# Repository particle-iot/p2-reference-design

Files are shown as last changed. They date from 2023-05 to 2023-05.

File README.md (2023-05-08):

# P2 evaluation board reference design

This board is a reference design for creating your own P2 base board. 

It is not available for purchase as a completed product; if you are interested in prototyping with the P2 we recommend using the Photon 2, which contains a P2 module on it, and has the same pinouts as the Feather connectors on this board.

This is a simple breakout board for Particle's P2 Wi-Fi module. It breaks out all of its pins via easy to use headers. The board features a USB port, a barrel jack power connector, buttons, and RGB LED as well as Feather, Grove, and Qwiic connectors for prototyping with external sensors, displays, etc..

- [P2 Datasheet](https://docs.particle.io/reference/datasheets/wi-fi/p2-datasheet/)
- [Particle hardware library for Eagle CAD](https://github.com/particle-iot/hardware-libraries)

## Schematic

The schematic files (*.sch) in Eagle CAD format are included in the **eagle** directory in this repository.

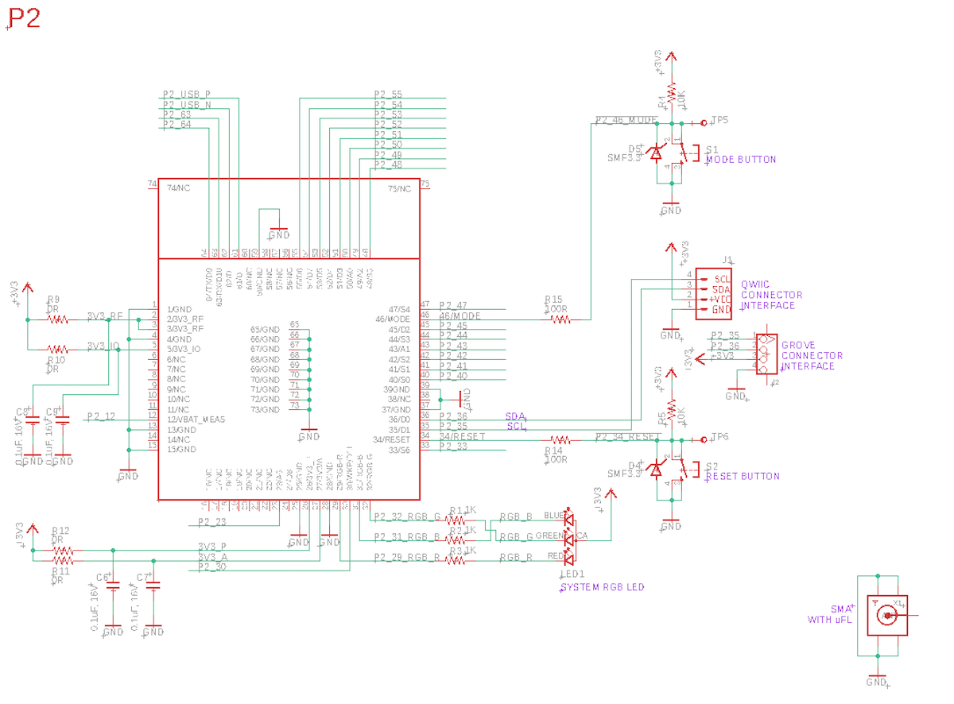
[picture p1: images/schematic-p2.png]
Schematic P2


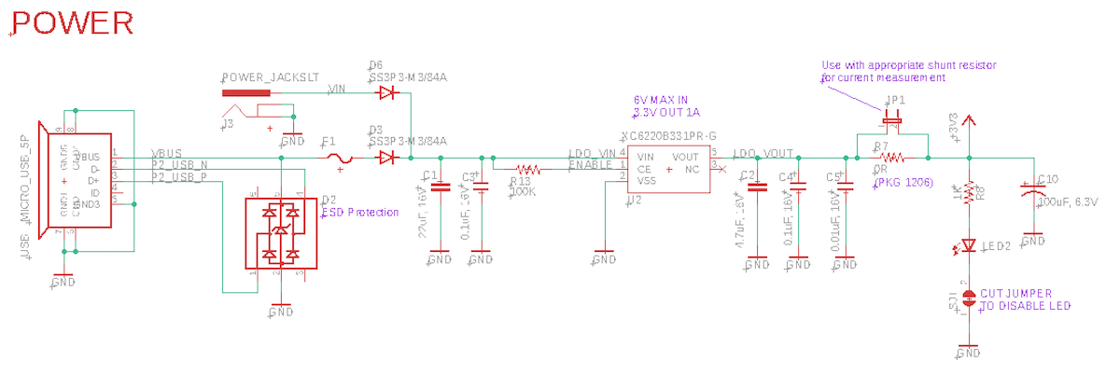
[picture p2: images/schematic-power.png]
Power


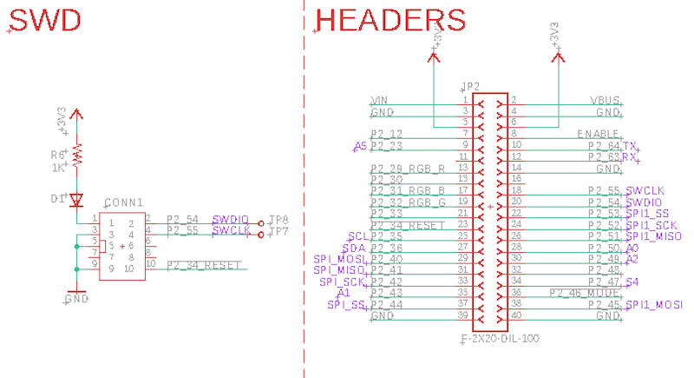
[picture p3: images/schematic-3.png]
SWD and Headers


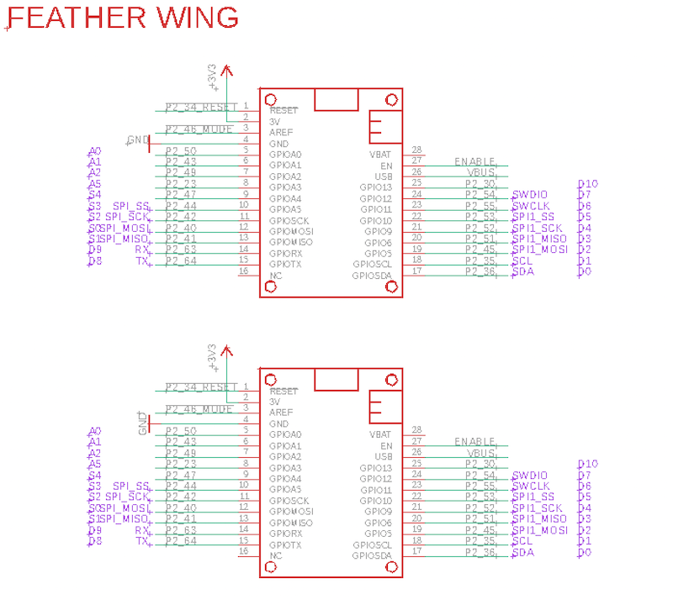
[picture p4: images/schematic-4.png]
Feather


## Board layout

The board layout files (*.brd) in Eagle CAD format are included in the **eagle** directory in this repository. 

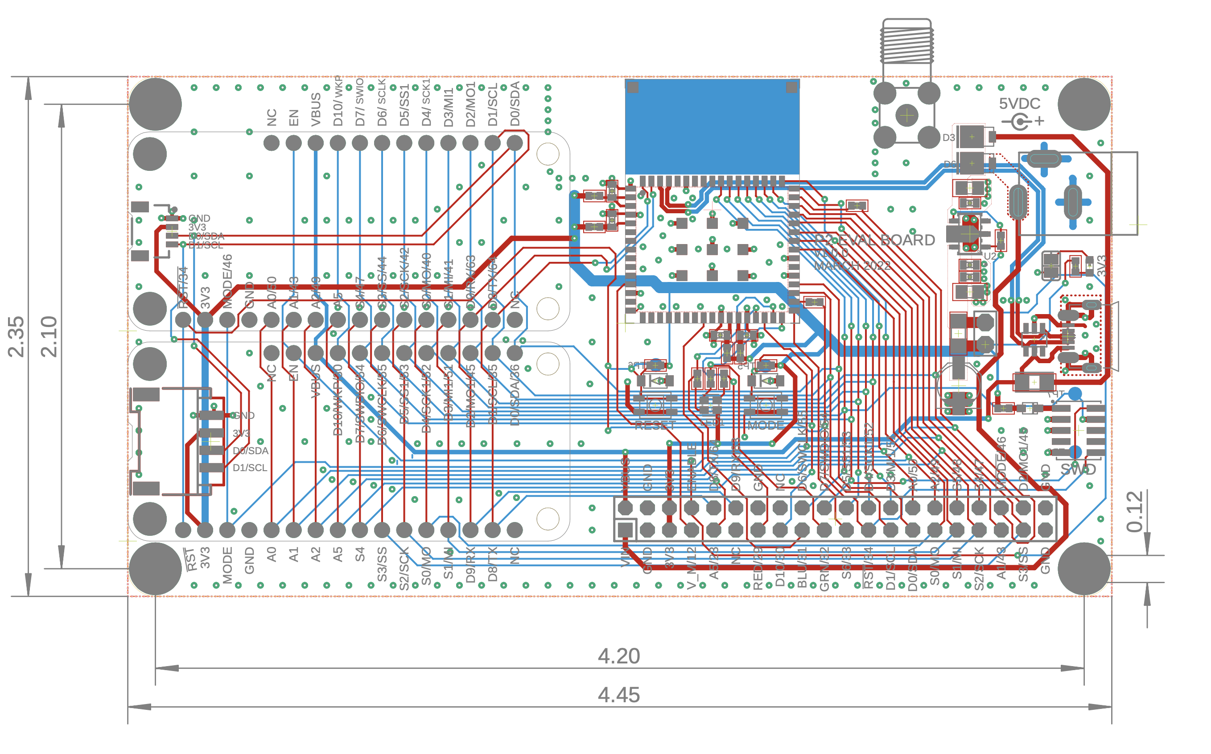
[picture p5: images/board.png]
Board layout


This is a 4-layer board, so you won't be able to edit the board using the free version of Autodesk Eagle, however gerber files are included in the **gerbers** directory if you want to fabricate this exact board.

The recommended stack-up is:

- DIELECTRIC = 3.61 at 1GHz
- TOP LAYER = 1.7MIL (1 OZ)
- PREPEG = 7.96MIL
- LAYER 2 = 0.68MIL (0.5 OZ)
- CORE = 47MIL
- LAYER 3 = 0.68MIL (0.5 OZ)
- PREPEG = 7.96MIL
- BOTTOM LAYER = 1.7MIL (1 OZ)

## Description

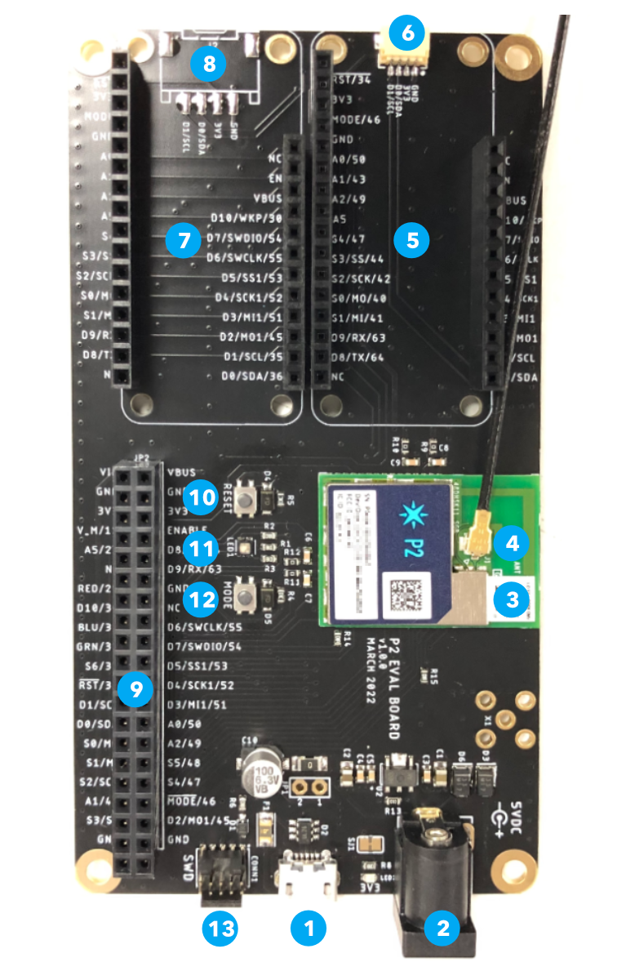
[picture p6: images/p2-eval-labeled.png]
Board labeeled


| Label | Description |
| :---: | :--- |
| 1 | USB |
| 2 | 5V Power In (optional) |
| 3 | P2 Module |
| 4 | External Wi-Fi and BLE antenna (optional) |
| 5 | Feather expansion connector |
| 6 | Qwiic I2C connector |
| 7 | Feather expansion connector |
| 8 | Grove expansion connector |
| 9 | Expansion header|
| 10 | RESET button |
| 11 | RGB LED |
| 12 | MODE button|
| 13 | SWD debugging connector |

If powering by USB, 500 mA is required. This a compatible with most USB hubs, computers, laptops, and chargers, but will not work with some low-power USB ports on some keyboards.
 
The P2 includes a built-in trace antenna that is used for both BLE and Wi-Fi. A U.FL connector is provided for an external antenna, if desired. The antenna selection must be made in software; the P2 will not automatically switch between built-in and external antennas. If using an external antenna, a dual-band (2.4 GHz and 5 GHz) antenna is required. The external antenna doesn't have to explicitly include BLE support, as the BLE frequencies are the same as 2.4 GHz Wi-Fi so all dual-band Wi-Fi antennas are compatible.

## Building user firmware

As of the time of writing (June 2022), P2 firmware can only be compiled using the cloud compiler.

### Using Particle Workbench

When using Particle Workbench, use the **Particle: Launch CLI** option from the Command Palette (Command-Shift-P or Ctrl-Shift-P). Then use the Particle CLI to generate a binary, as described in the next section.

### Using the Particle CLI

From the Particle CLI, you can use a command such as:

```
particle compile p2 . --target 5.3.1 --saveTo firmware.bin
```

Note that you must specify a target system version when building for the P2. If an upgrade of Device OS is required, it will be updated OTA.

### Using the Web IDE

From the Web IDE, select the Devices icon, then your P2 device, then target an appropriate firmware version, such as 5.3.1. If an upgrade of Device OS is required, it will be updated OTA.

## Expansion connectors

### Expansion header

If you are prototyping your own custom design you may want to use the 40-pin expansion header. It's a standard 20x2 female header, 0.1" pitch, that can accept male header pins or prototyping wires.
    
Expansion header

See the [P2 Datasheet](https://docs.particle.io/reference/datasheets/wi-fi/p2-datasheet/) for details about the pins. The gold boxes indicate the P2 pin numbers.

### Feather expansion

Feather connector

There are two socket for [Feather accessory boards](https://docs.particle.io/hardware/expansion/feather/). These are only for use with displays, sensors, storage, etc.. 

You must not plug a Particle device such as an Argon or Boron in this socket, as the device may be permanently damaged.

This will work with most Feather boards, however:

- The P2 does not support ADC inputs A3, A4, and A5.
- The P2 does not work with Feather accessories that use SPI1 on the Argon or Boron D pins.
- Some pins have different names which may require minor source code modifications. This includes and code that used Argon or Boron pins A3, A4, A5, or D8.

The pinouts of the Feather accessory socket correspond to pinouts of the Photon 2. See the [Photon 2 Datasheet](https://docs.particle.io/reference/datasheets/wi-fi/photon-2-datasheet/) and the [Argon to Photon 2 migration guide](https://docs.particle.io/hardware/migration-guides/photon-2-argon-migration-guide/) for more information.

Some pins in the same positions are named differently between the Argon/Boron and the Feather accessory socket/Photon 2:

| Argon Name | P2 Feather Socket Name |
| :---: | :---: |
| A3 | A5 |
| A4 | S4 |
| A5 | S3 |
| D8 | D10 |

Additionally, `D` pin aliases `D8` and higher are different, however these names are rarely used.

Photon 2 vs. Argon Comparison

### Qwiic connector

[Qwiic](https://docs.particle.io/hardware/expansion/qwiic/) is a 3.3V I2C standard developed by SparkFun and adopted by other manufacturers. It's also compatible with Adafruit Stemma Qt expansion devices. You can use this to add displays, sensors, etc. and multiple devices can be connected to a single Qwiic port, as accessory boards have two connectors for chaining multiple sensors.

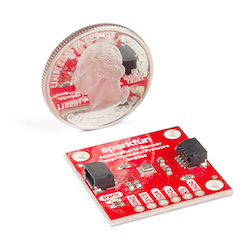
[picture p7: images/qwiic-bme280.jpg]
Qwiic sensor


### Grove connector

The Grove connector allows [Grove accessories](https://docs.particle.io/reference/datasheets/accessories/gen3-accessories/#grove-starter-kit) to be added. Pins D0 and D1 are present on the connector. This allows the use of Grove I2C sensors.

If you are not using I2C elsewhere (Feather, Qwiic), you can use these pins as digital GPIO, or as analog inputs.

| Pin | I2C | Digital | Analog |
| :---: | :---: | :---: | :---: |
| GND | | | |
| 3V3 | | | |
| D0/SDA | SDA | D0 | A3 |
| D1/SCL | SCL | D1 | A4 |

Grove sensor

## SWD debugging connector

The P2 eval board has a 10 pin debug connector that exposes the SWD interface of the MCU. This can be used to program the bootloader, device OS, or the user firmware using any standard SWD tools including the Particle Debugger, Segger J/LINK, or other CMSIS-DAP debuggers. It can also be used for source-level debugging using Particle Workbench.

Note that SWD is shared with GPIO pins D6 and D7, and by default SWD is only enabled while the bootloader is running, immediately at boot, and when in DFU mode (blinking yellow). Only Debug builds in Workbench have SWD enabled in when user firmware is running.

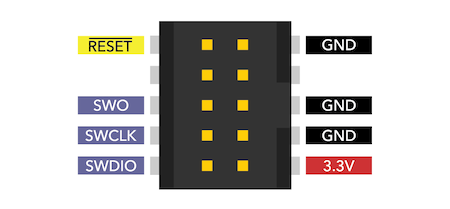
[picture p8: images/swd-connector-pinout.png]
SWD connector


The SWO pin is not used on the P2.

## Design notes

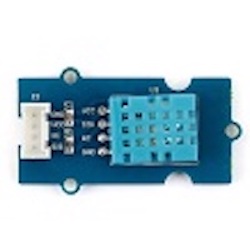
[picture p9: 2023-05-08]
images/temphumi.jpeg

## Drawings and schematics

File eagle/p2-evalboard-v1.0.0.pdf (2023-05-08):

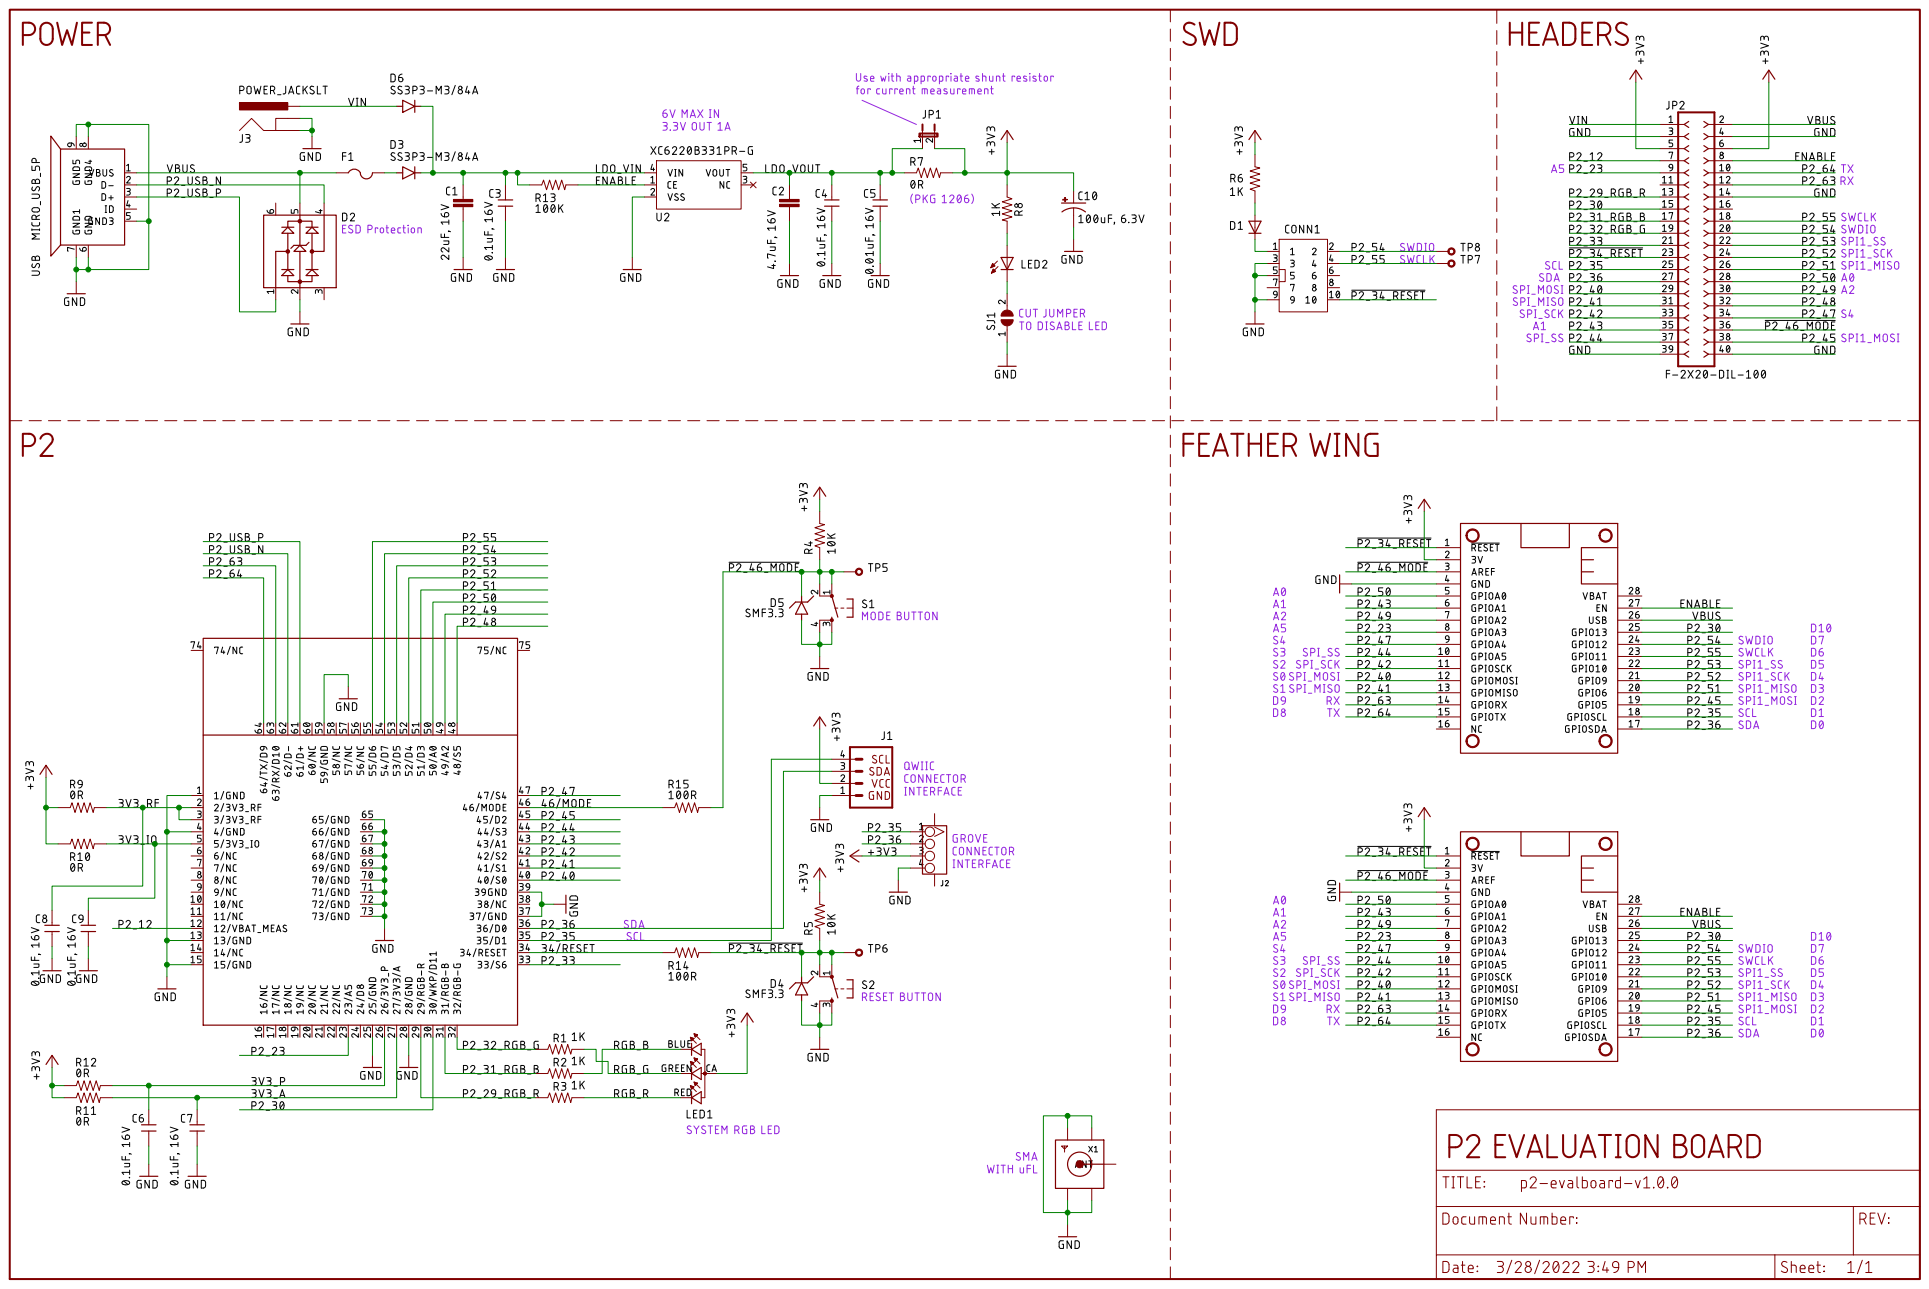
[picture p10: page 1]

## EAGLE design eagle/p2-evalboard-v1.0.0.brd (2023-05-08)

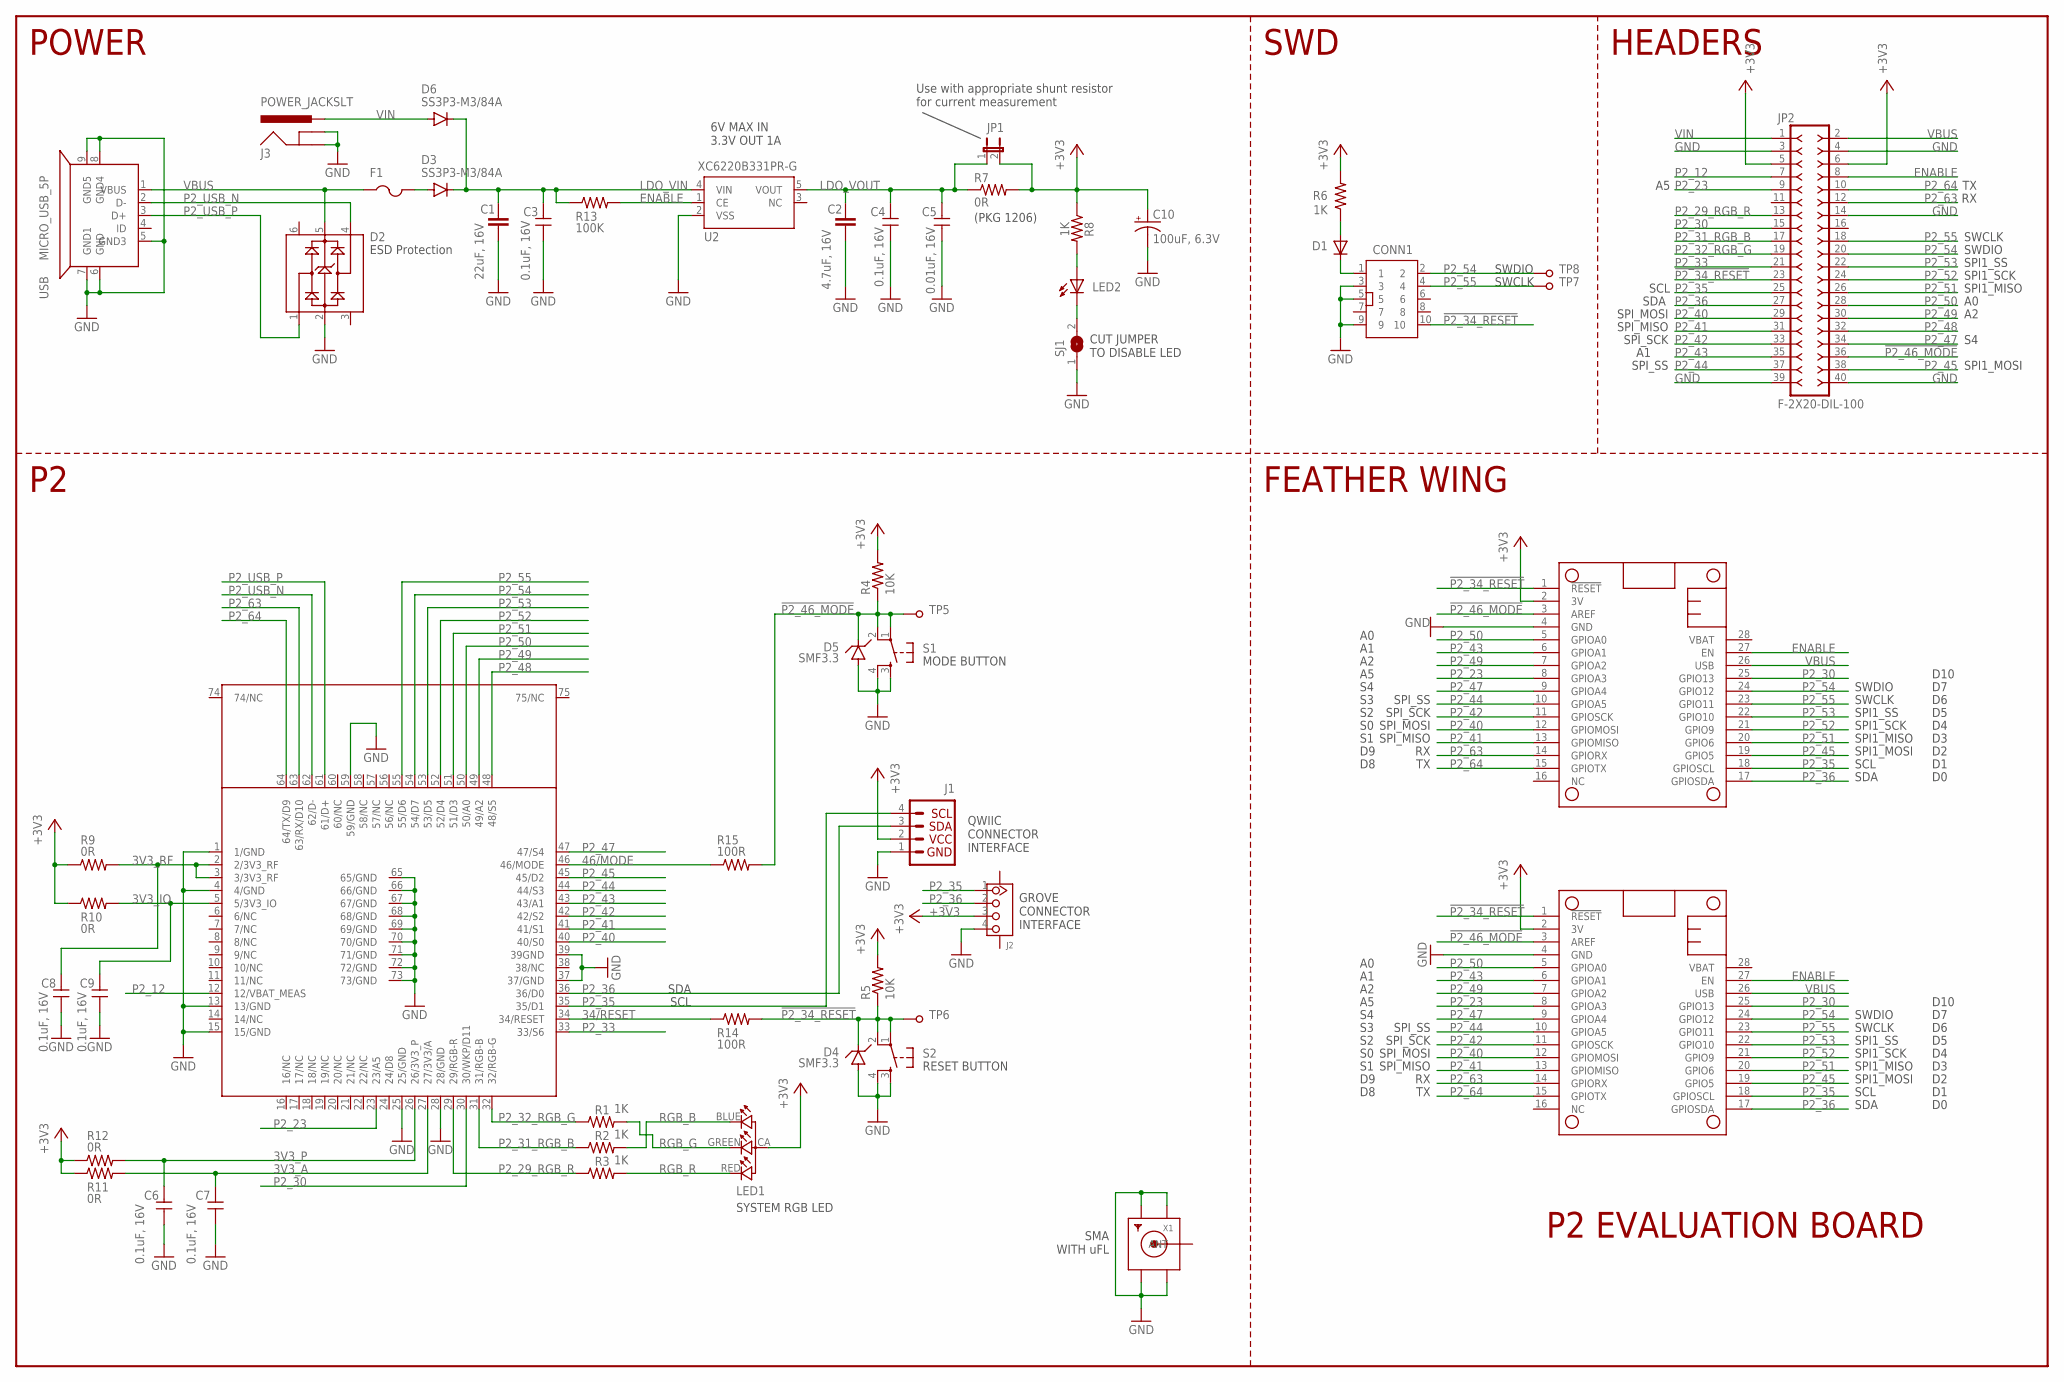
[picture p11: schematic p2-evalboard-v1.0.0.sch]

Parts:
C1: 22uF, 16V; C0805
C2: 4.7uF, 16V; C0805
C3, C4, C6, C7, C8, C9: 0.1uF, 16V; C0603_P
C5: 0.01uF, 16V; C0603_P
C10: 100uF, 6.3V; PANASONIC_C
CONN1: CONN5X2; CONN5X2_1.27
D1: DIODESOD-323F; SOD-323F
D2: MAX3207EAUT+T; SOT23-6
D3, D6: SS3P3-M3/84A; DIODE-DO-220AA(SMP)
D4, D5: SMF3.3; SOD-123FL
F1: PTCFUSE-1206; R1206
J1: QWIIC_CONNECTORJS-1MM; 1X04_1MM_RA
J2: 4P-SMD-2.0-90D; HW4-SMD-2.0-90D
J3: POWER_JACKSLT; POWER_JACK_SLOT
JP1: JUMPER2
JP2: F-2X20-DIL-100; DIL-100-2X20
LED1: RGB-LED-CLMVB-FKARGB; PLCC4-2MM-RGB
LED2: LEDCHIPLED_0603; CHIPLED_0603
MS1, MS2: FEATHERWING_NODIM; FEATHERWING_DIM
R1, R2, R3, R6, R8: 1K; R0603_P
R4, R5: 10K; R0603_P
R7: 0R; R1206
R9, R10, R11, R12: 0R; R0603_P
R13: 100K; R0603_P
R14, R15: 100R; R0603_P
S1, S2: TAC_SWITCHSMD; TACTILE_SWITCH_SMD
SJ1: SOLDERJUMPERCLOSED; SOLDERJUMPER_CLOSEDWIRE
TP5, TP6, TP7, TP8: TP-1.5MM; TP
U1: P2; TRON
U2: XC6220B331PR-G; SOT-89-5_TOR-M
USB: MICRO_USB_5P; MICRO_USB
X1: SMACONNECTOR; SMA90_DIP

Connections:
3V3_A: C7.2, R11.2, U1.27 (27/3V3/A)
3V3_IO: C9.2, R10.2, U1.5 (5/3V3_IO)
3V3_P: C6.2, R12.2, U1.26 (26/3V3_P)
3V3_RF: C8.2, R9.2, U1.2 (2/3V3_RF), U1.3 (3/3V3_RF)
34/RESET: R14.1, U1.34 (34/RESET)
46/MODE: R15.1, U1.46 (46/MODE)
!P2_34_RESET: CONN1.10, D4.C, JP2.23, MS1.1 (!RESET), MS2.1 (!RESET), R5.1, R14.2, S2.1, S2.2, TP6.TP
!P2_46_MODE: D5.C, JP2.36, MS1.3 (AREF), MS2.3 (AREF), R4.1, R15.2, S1.1, S1.2, TP5.TP
+3V3: C10.+, J1.2 (VCC), J2.3, JP1.2, JP2.5, JP2.6, LED1.CA (1), MS1.2 (3V), MS2.2 (3V), R4.2, R5.2, R6.2, R7.2, R8.1, R9.1, R10.1, R11.1, R12.1
ENABLE: JP2.8, MS1.27 (EN), MS2.27 (EN), R13.2, U2.1 (CE)
GND: C1.2, C2.2, C3.1, C4.1, C5.1, C6.1, C7.1, C8.1, C9.1, C10.-, CONN1.3, CONN1.5, CONN1.9, D2.2, D4.A, D5.A, J1.1 (GND), J2.4, J3.GND@1 (GNDBREAK), J3.GND@2 (GND), JP2.3, JP2.4, JP2.14, JP2.39, JP2.40, MS1.4 (GND), MS2.4 (GND), S1.3, S1.4, S2.3, S2.4, SJ1.1, U1.1 (1/GND), U1.4 (4/GND), U1.13 (13/GND), U1.15 (15/GND), U1.25 (25/GND), U1.28 (28/GND), U1.37 (37/GND), U1.39 (39GND), U1.59 (59/GND), U1.65 (65/GND), U1.66 (66/GND), U1.67 (67/GND), U1.68 (68/GND), U1.69 (69/GND), U1.70 (70/GND), U1.71 (71/GND), U1.72 (72/GND), U1.73 (73/GND), U2.2 (VSS), USB.5 (GND3), USB.6 (GND), USB.7 (GND1), USB.8 (GND4), USB.9 (GND5), X1.GND1, X1.GND2, X1.GND3, X1.GND4
LDO_VIN: C1.1, C3.2, D3.CATHODE, D6.CATHODE, R13.1, U2.4 (VIN)
LDO_VOUT: C2.1, C4.2, C5.2, JP1.1, R7.1, U2.5 (VOUT)
unnamed: CONN1.1, D1.C
unnamed: D1.A, R6.1
unnamed: LED2.C, SJ1.2
unnamed: D3.ANODE, F1.2
unnamed: LED2.A, R8.2
P2_12: JP2.7, U1.12 (12/VBAT_MEAS)
P2_23: JP2.9, MS1.8 (GPIOA3), MS2.8 (GPIOA3), U1.23 (23/A5)
P2_29_RGB_R: JP2.13, R3.1, U1.29 (29/RGB-R)
P2_30: JP2.15, MS1.25 (GPIO13), MS2.25 (GPIO13), U1.30 (30/WKP/D11)
P2_31_RGB_B: JP2.17, R2.1, U1.31 (31/RGB-B)
P2_32_RGB_G: JP2.19, R1.1, U1.32 (32/RGB-G)
P2_33: JP2.21, U1.33 (33/S6)
P2_35: J1.4 (SCL), J2.1, JP2.25, MS1.18 (GPIOSCL), MS2.18 (GPIOSCL), U1.35 (35/D1)
P2_36: J1.3 (SDA), J2.2, JP2.27, MS1.17 (GPIOSDA), MS2.17 (GPIOSDA), U1.36 (36/D0)
P2_40: JP2.29, MS1.12 (GPIOMOSI), MS2.12 (GPIOMOSI), U1.40 (40/S0)
P2_41: JP2.31, MS1.13 (GPIOMISO), MS2.13 (GPIOMISO), U1.41 (41/S1)
P2_42: JP2.33, MS1.11 (GPIOSCK), MS2.11 (GPIOSCK), U1.42 (42/S2)
P2_43: JP2.35, MS1.6 (GPIOA1), MS2.6 (GPIOA1), U1.43 (43/A1)
P2_44: JP2.37, MS1.10 (GPIOA5), MS2.10 (GPIOA5), U1.44 (44/S3)
P2_45: JP2.38, MS1.19 (GPIO5), MS2.19 (GPIO5), U1.45 (45/D2)
P2_47: JP2.34, MS1.9 (GPIOA4), MS2.9 (GPIOA4), U1.47 (47/S4)
P2_48: JP2.32, U1.48 (48/S5)
P2_49: JP2.30, MS1.7 (GPIOA2), MS2.7 (GPIOA2), U1.49 (49/A2)
P2_50: JP2.28, MS1.5 (GPIOA0), MS2.5 (GPIOA0), U1.50 (50/A0)
P2_51: JP2.26, MS1.20 (GPIO6), MS2.20 (GPIO6), U1.51 (51/D3)
P2_52: JP2.24, MS1.21 (GPIO9), MS2.21 (GPIO9), U1.52 (52/D4)
P2_53: JP2.22, MS1.22 (GPIO10), MS2.22 (GPIO10), U1.53 (53/D5)
P2_54: CONN1.2, JP2.20, MS1.24 (GPIO12), MS2.24 (GPIO12), TP8.TP, U1.54 (54/D7)
P2_55: CONN1.4, JP2.18, MS1.23 (GPIO11), MS2.23 (GPIO11), TP7.TP, U1.55 (55/D6)
P2_63: JP2.12, MS1.14 (GPIORX), MS2.14 (GPIORX), U1.63 (63/RX/D10)
P2_64: JP2.10, MS1.15 (GPIOTX), MS2.15 (GPIOTX), U1.64 (64/TX/D9)
P2_USB_N: D2.4, U1.62 (62/D-), USB.2 (D-)
P2_USB_P: D2.1, U1.61 (61/D+), USB.3 (D+)
RGB_B: LED1.BLUE (2), R2.2
RGB_G: LED1.GREEN (3), R1.2
RGB_R: LED1.RED (4), R3.2
VBUS: D2.5, F1.1, JP2.2, MS1.26 (USB), MS2.26 (USB), USB.1 (VBUS)
VIN: D6.ANODE, J3.PWR, JP2.1

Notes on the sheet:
(PKG 1206)
CUT JUMPER TO DISABLE LED
Use with appropriate shunt resistor for current measurement
ESD Protection
QWIIC CONNECTOR INTERFACE
SMA WITH uFL
SDA
SCL
P2 EVALUATION BOARD
6V MAX IN 3.3V OUT 1A
SYSTEM RGB LED
MODE BUTTON
RESET BUTTON
SWDIO
SWCLK
SPI_MISO
SPI_MOSI
SPI_SCK
SPI_SS
POWER
SWD
FEATHER WING
GROVE CONNECTOR INTERFACE
SPI1_SCK
SPI1_MOSI
SPI1_MISO
SPI1_SS
D10
HEADERS

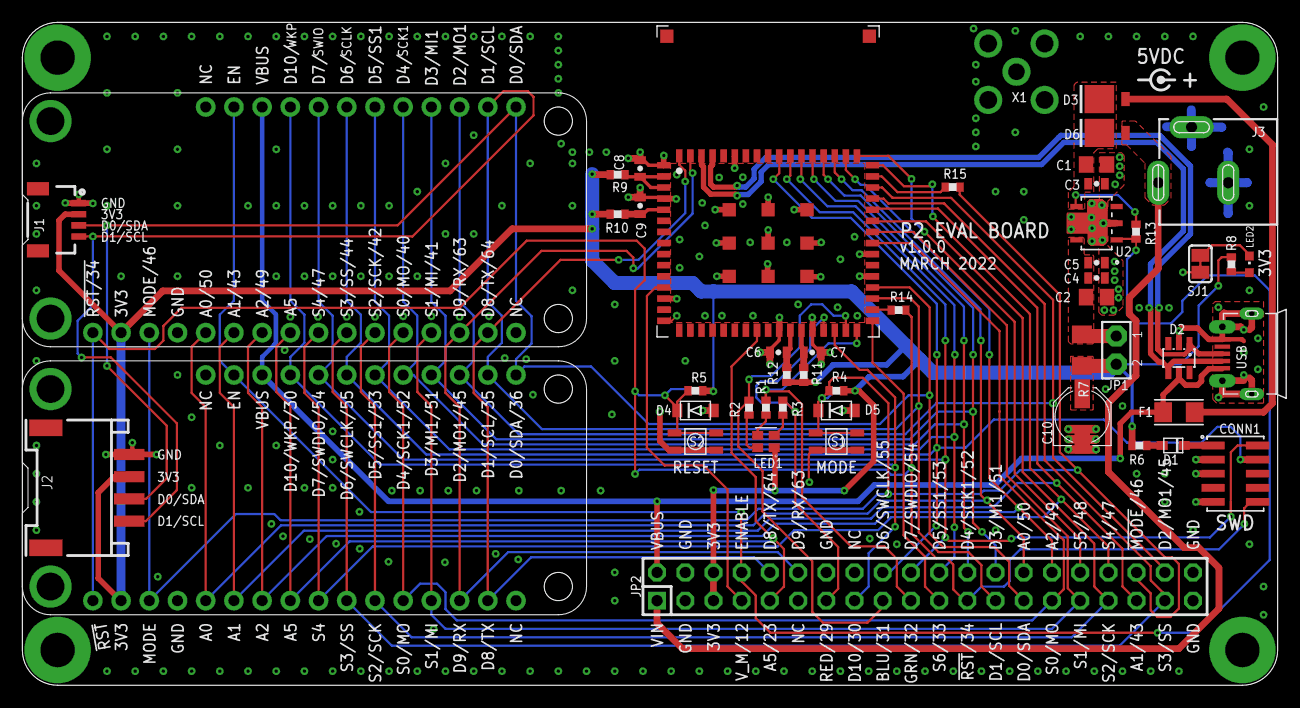
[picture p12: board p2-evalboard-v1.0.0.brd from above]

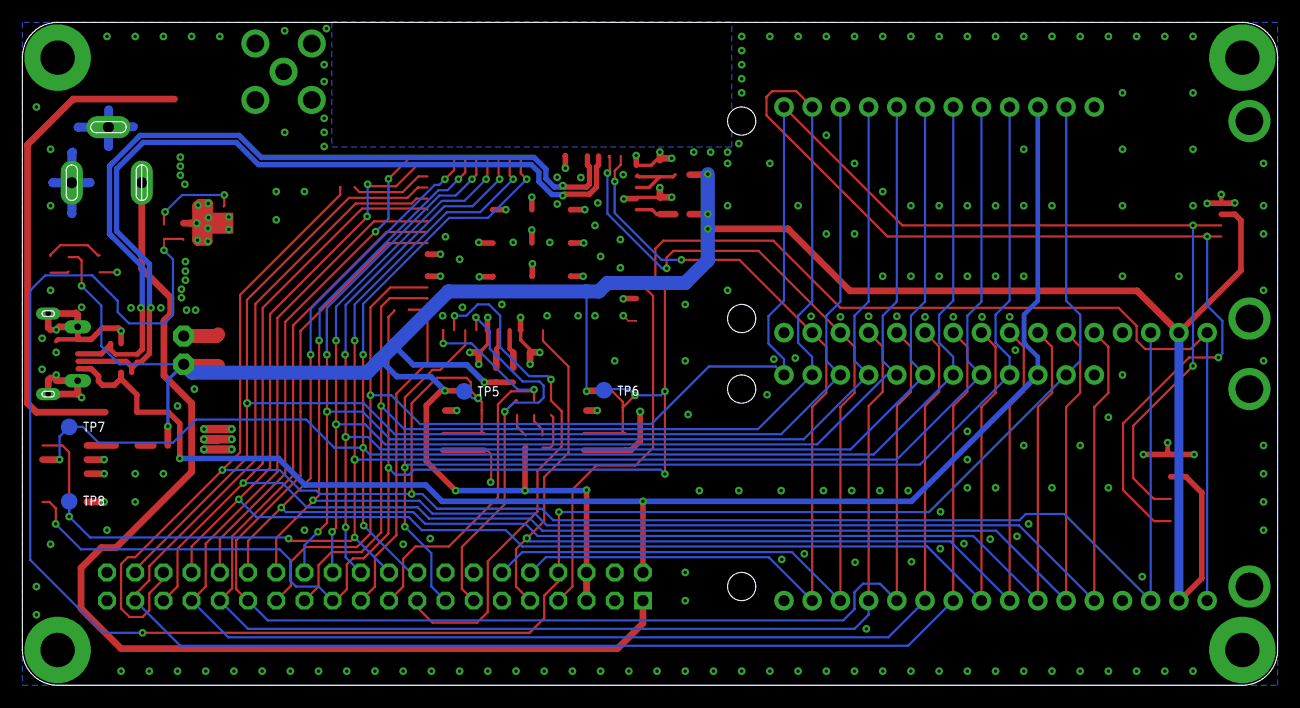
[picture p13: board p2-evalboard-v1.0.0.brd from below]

Board: 4 copper layers, 113.0 x 59.7 mm, 53 parts (4 on the bottom side), 51 nets.

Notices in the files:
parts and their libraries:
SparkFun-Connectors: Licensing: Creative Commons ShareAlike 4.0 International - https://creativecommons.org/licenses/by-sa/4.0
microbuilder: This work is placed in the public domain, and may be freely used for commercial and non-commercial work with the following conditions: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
